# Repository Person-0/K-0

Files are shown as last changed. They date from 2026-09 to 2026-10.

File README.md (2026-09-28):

# **K-0**

75% Keyboard with thocky switches. USB-C / BLE connectivity, fully custom 3d printed case + PCB.

## The Idea

Always wanted to design a keyboard for myself. Decided to finally go for it.

After searching online about various keyboards and switches, I realized I love deep thocky-sounding keyboards, so I selected the `Akko Bittersweet` switches. They are tactile switches with an operating force of 48 ± 5gf and tactile force of 60 ± 5gf. ([more switch specs](https://en.akkogear.com/product/bittersweet-switch-lubed/), [sound test](https://www.youtube.com/watch?v=nj9W8xXELII)).

The layout of the keyboard will be 60%, with no separate arrow keys or navigation cluster BUT with an added function keys row.

The microcontroller I have selected for this project is the `MDBT50Q-P1M nRF52840 Based BLE Module` for it's built-in bluetooth capabilities and good support ecosystem for similar projects. This will be paired up with a 1s (3.7V) LiPo battery with a suitable capacity + custom charging circuit which will be good enough for our usecase.

### Keyboard layout (from [keyboard-layout-editor.com](https://keyboard-layout-editor.com)):
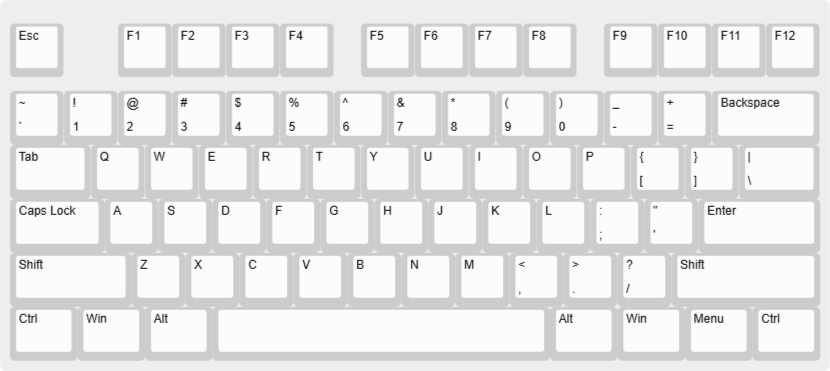
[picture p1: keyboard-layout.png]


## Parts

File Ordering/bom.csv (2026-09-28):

Reference | Qty | Value | Footprint | Datasheet | Manufacturer_Part_Number
C1,C2 | 2 | 1uF | Capacitor_SMD:C_0402_1005Metric | https://prod-parts-data.s3.amazonaws.com/CC0402KRX5R6BB105/datasheet/1_CC0402KRX5R6BB105-Yageo-datasheet-8324442.pdf | CC0402KRX5R6BB105
C3,C4 | 2 | 10uF | Capacitor_SMD:C_0402_1005Metric | https://prod-parts-data.s3.amazonaws.com/CC0402MRX5R5BB106/datasheet/1_CC0402MRX5R5BB106-Yageo-datasheet-140260304.pdf | CC0402MRX5R5BB106
C5 | 1 | 0.1uF | Capacitor_SMD:C_0402_1005Metric | https://prod-parts-data.s3.amazonaws.com/MC0402B104K160CT/datasheet/1_MC0402B104K160CT-Multicomp-datasheet-38887781.pdf | MC0402B104K160CT
D2,D3,D4,D5,D6,D7,D8,D9,D10,D11,D12,D13,D14,D15,D16,D17,D18,D19,D20,D21,D22,D23,D24,D25,D26,D27,D28,D29,D30,D31,D32,D33,D34,D35,D36,D37,D38,D39,D40,D41,D42,D43,D44,D45,D46,D47,D48,D49,D50,D51,D52,D53,D54,D55,D56,D57,D58,D59,D60,D61,D62,D63,D64,D65,D66,D67,D68,D69,D70,D73,D74,D75,D77,D81 | 74 | 1N4148WS | Diode_SMD:D_SOD-323F | https://prod-parts-data.s3.amazonaws.com/1N4148WS/datasheet/1_1N4148WS-ON-Semiconductor-datasheet-154551630.pdf | 1N4148WS
IC1 | 1 | BQ24040DSQR | BQ24040DSQR-lion:SON40P200X200X80-11N | http://www.ti.com/lit/gpn/bq24040 | BQ24040DSQR
IC2 | 1 | TPS63031DSKR | TPS63031DSKR-lion:SON50P250X250X80-11N-D | http://www.ti.com/general/docs/suppproductinfo.tsp?distId=10 | TPS63031DSKR
J1 | 1 | Display | Connector_PinHeader_2.54mm:PinHeader_1x08_P2.54mm_Vertical | ~
J2 | 1 | USB4216-03-A | USB421603A |  | USB4216-03-A
J4 | 1 | PG_LED | Connector_PinHeader_2.54mm:PinHeader_1x02_P2.54mm_Vertical | ~
J5 | 1 | CHRG_LED | Connector_PinHeader_2.54mm:PinHeader_1x02_P2.54mm_Vertical | ~
J6 | 1 | POWER_LED | Connector_PinHeader_2.54mm:PinHeader_1x02_P2.54mm_Vertical | ~
J7 | 1 | Mode Selector | Connector_PinHeader_2.54mm:PinHeader_1x03_P2.54mm_Vertical | ~
J8 | 1 | Mode Selector | Connector_PinHeader_2.54mm:PinHeader_1x04_P2.54mm_Vertical | ~
L2 | 1 | LPS3015-222MRC | LPS3015-222MRC:IND_LPS3015-222MRC | https://prod-parts-data.s3.amazonaws.com/LPS3015-222MRC/datasheet/1_LPS3015-222MRC-Coilcraft-datasheet-10792063.pdf | LPS3015-222MRC
MDBT50Q_1 | 1 | MDBT50Q_1 | RF_Module:Raytac_MDBT50Q | https://www.mouser.in/datasheet/3/1361/1/nRF52840_MDBT50Q_1MV2_MDBT50Q_P1MV2_Ver.L_spec.pdf | 113990583
R1,R2 | 2 | 5.1k | Resistor_SMD:R_0402_1005Metric | https://prod-parts-data.s3.amazonaws.com/CR0402-JW-512GLF/datasheet/1_CR0402-JW-512GLF-Bourns-datasheet-8723995.pdf | CR0402-JW-512GLF
R3 | 1 | 1k | Connector_PinHeader_2.54mm:PinHeader_1x02_P2.54mm_Vertical
R4 | 1 | 2k | Connector_PinHeader_2.54mm:PinHeader_1x02_P2.54mm_Vertical
R5 | 1 | 10k | Connector_PinHeader_2.54mm:PinHeader_1x02_P2.54mm_Vertical
R6,R7,R8 | 3 | 330 | Connector_PinHeader_2.54mm:PinHeader_1x02_P2.54mm_Vertical
R9 | 1 | 300k | Connector_PinHeader_2.54mm:PinHeader_1x02_P2.54mm_Vertical
R10 | 1 | 400k | Connector_PinHeader_2.54mm:PinHeader_1x02_P2.54mm_Vertical
SW1 | 1 | RotaryEncoder_Switch | Rotary_Encoder:RotaryEncoder_Alps_EC11E-Switch_Vertical_H20mm | ~
SW2 | 1 | ESC | Button_Switch_Keyboard:SW_Cherry_MX_1.00u_PCB | ~
SW3 | 1 | TILDE | Button_Switch_Keyboard:SW_Cherry_MX_1.00u_PCB | ~
SW4 | 1 | TAB | Button_Switch_Keyboard:SW_Cherry_MX_1.50u_PCB | ~
SW5 | 1 | CAPS | Button_Switch_Keyboard:SW_Cherry_MX_1.75u_PCB | ~
SW6 | 1 | LSHIFT | Button_Switch_Keyboard:SW_Cherry_MX_2.25u_PCB | ~
SW7 | 1 | LCTRL | Button_Switch_Keyboard:SW_Cherry_MX_1.25u_PCB | ~
SW8 | 1 | 1 | Button_Switch_Keyboard:SW_Cherry_MX_1.00u_PCB | ~
SW9 | 1 | Q | Button_Switch_Keyboard:SW_Cherry_MX_1.00u_PCB | ~
SW10 | 1 | A | Button_Switch_Keyboard:SW_Cherry_MX_1.00u_PCB | ~
SW11 | 1 | Z | Button_Switch_Keyboard:SW_Cherry_MX_1.00u_PCB | ~
SW12 | 1 | WIN | Button_Switch_Keyboard:SW_Cherry_MX_1.25u_PCB | ~
SW13 | 1 | F1 | Button_Switch_Keyboard:SW_Cherry_MX_1.00u_PCB | ~
SW14 | 1 | 2 | Button_Switch_Keyboard:SW_Cherry_MX_1.00u_PCB | ~
SW15 | 1 | W | Button_Switch_Keyboard:SW_Cherry_MX_1.00u_PCB | ~
SW16 | 1 | S | Button_Switch_Keyboard:SW_Cherry_MX_1.00u_PCB | ~
SW17 | 1 | X | Button_Switch_Keyboard:SW_Cherry_MX_1.00u_PCB | ~
SW18 | 1 | LALT | Button_Switch_Keyboard:SW_Cherry_MX_1.25u_PCB | ~
SW19 | 1 | F2 | Button_Switch_Keyboard:SW_Cherry_MX_1.00u_PCB | ~
SW20 | 1 | 3 | Button_Switch_Keyboard:SW_Cherry_MX_1.00u_PCB | ~
SW21 | 1 | E | Button_Switch_Keyboard:SW_Cherry_MX_1.00u_PCB | ~
SW22 | 1 | D | Button_Switch_Keyboard:SW_Cherry_MX_1.00u_PCB | ~
SW23 | 1 | C | Button_Switch_Keyboard:SW_Cherry_MX_1.00u_PCB | ~
SW24 | 1 | SPACE | Button_Switch_Keyboard:SW_Cherry_MX_6.25u_PCB | ~
SW25 | 1 | F3 | Button_Switch_Keyboard:SW_Cherry_MX_1.00u_PCB | ~
SW26 | 1 | 4 | Button_Switch_Keyboard:SW_Cherry_MX_1.00u_PCB | ~
SW27 | 1 | R | Button_Switch_Keyboard:SW_Cherry_MX_1.00u_PCB | ~
SW28 | 1 | F | Button_Switch_Keyboard:SW_Cherry_MX_1.00u_PCB | ~
SW29 | 1 | V | Button_Switch_Keyboard:SW_Cherry_MX_1.00u_PCB | ~
SW30 | 1 | F4 | Button_Switch_Keyboard:SW_Cherry_MX_1.00u_PCB | ~
SW31 | 1 | 5 | Button_Switch_Keyboard:SW_Cherry_MX_1.00u_PCB | ~
SW32 | 1 | T | Button_Switch_Keyboard:SW_Cherry_MX_1.00u_PCB | ~
SW33 | 1 | G | Button_Switch_Keyboard:SW_Cherry_MX_1.00u_PCB | ~
SW34 | 1 | B | Button_Switch_Keyboard:SW_Cherry_MX_1.00u_PCB | ~
SW35 | 1 | 6 | Button_Switch_Keyboard:SW_Cherry_MX_1.00u_PCB | ~
SW36 | 1 | Y | Button_Switch_Keyboard:SW_Cherry_MX_1.00u_PCB | ~
SW37 | 1 | H | Button_Switch_Keyboard:SW_Cherry_MX_1.00u_PCB | ~
SW38 | 1 | N | Button_Switch_Keyboard:SW_Cherry_MX_1.00u_PCB | ~
SW39 | 1 | F5 | Button_Switch_Keyboard:SW_Cherry_MX_1.00u_PCB | ~
SW40 | 1 | 7 | Button_Switch_Keyboard:SW_Cherry_MX_1.00u_PCB | ~
SW41 | 1 | U | Button_Switch_Keyboard:SW_Cherry_MX_1.00u_PCB | ~
SW42 | 1 | J | Button_Switch_Keyboard:SW_Cherry_MX_1.00u_PCB | ~
SW43 | 1 | M | Button_Switch_Keyboard:SW_Cherry_MX_1.00u_PCB | ~
SW44 | 1 | F6 | Button_Switch_Keyboard:SW_Cherry_MX_1.00u_PCB | ~
SW45 | 1 | 8 | Button_Switch_Keyboard:SW_Cherry_MX_1.00u_PCB | ~
SW46 | 1 | I | Button_Switch_Keyboard:SW_Cherry_MX_1.00u_PCB | ~
SW47 | 1 | K | Button_Switch_Keyboard:SW_Cherry_MX_1.00u_PCB | ~
SW48 | 1 | COMMA | Button_Switch_Keyboard:SW_Cherry_MX_1.00u_PCB | ~
SW49 | 1 | RALT | Button_Switch_Keyboard:SW_Cherry_MX_1.25u_PCB | ~
SW50 | 1 | F7 | Button_Switch_Keyboard:SW_Cherry_MX_1.00u_PCB | ~
SW51 | 1 | 9 | Button_Switch_Keyboard:SW_Cherry_MX_1.00u_PCB | ~
SW52 | 1 | O | Button_Switch_Keyboard:SW_Cherry_MX_1.00u_PCB | ~
SW53 | 1 | L | Button_Switch_Keyboard:SW_Cherry_MX_1.00u_PCB | ~
SW54 | 1 | DOT | Button_Switch_Keyboard:SW_Cherry_MX_1.00u_PCB | ~
SW55 | 1 | FN | Button_Switch_Keyboard:SW_Cherry_MX_1.25u_PCB | ~
SW56 | 1 | F8 | Button_Switch_Keyboard:SW_Cherry_MX_1.00u_PCB | ~
SW57 | 1 | 0 | Button_Switch_Keyboard:SW_Cherry_MX_1.00u_PCB | ~
SW58 | 1 | P | Button_Switch_Keyboard:SW_Cherry_MX_1.00u_PCB | ~
SW59 | 1 | SEMICOLON | Button_Switch_Keyboard:SW_Cherry_MX_1.00u_PCB | ~
SW60 | 1 | SLASH | Button_Switch_Keyboard:SW_Cherry_MX_1.00u_PCB | ~
SW61 | 1 | MENU | Button_Switch_Keyboard:SW_Cherry_MX_1.25u_PCB | ~
SW62 | 1 | MINUS | Button_Switch_Keyboard:SW_Cherry_MX_1.00u_PCB | ~
SW63 | 1 | SQBOPEN | Button_Switch_Keyboard:SW_Cherry_MX_1.00u_PCB | ~
SW64 | 1 | QUOTE | Button_Switch_Keyboard:SW_Cherry_MX_1.00u_PCB | ~
SW65 | 1 | RSHIFT | Button_Switch_Keyboard:SW_Cherry_MX_2.75u_PCB | ~
SW66 | 1 | RCTRL | Button_Switch_Keyboard:SW_Cherry_MX_1.25u_PCB | ~
SW67 | 1 | F9 | Button_Switch_Keyboard:SW_Cherry_MX_1.00u_PCB | ~
SW68 | 1 | EQUAL | Button_Switch_Keyboard:SW_Cherry_MX_1.00u_PCB | ~
SW69 | 1 | SQBCLOSE | Button_Switch_Keyboard:SW_Cherry_MX_1.00u_PCB | ~
SW70 | 1 | ENTER | Button_Switch_Keyboard:SW_Cherry_MX_2.25u_PCB | ~
SW73 | 1 | F10 | Button_Switch_Keyboard:SW_Cherry_MX_1.00u_PCB | ~
SW74 | 1 | BACKSPACE | Button_Switch_Keyboard:SW_Cherry_MX_2.00u_PCB | ~
SW75 | 1 | FWDSLASH | Button_Switch_Keyboard:SW_Cherry_MX_1.50u_PCB | ~
SW77 | 1 | F11 | Button_Switch_Keyboard:SW_Cherry_MX_1.00u_PCB | ~
SW81 | 1 | F12 | Button_Switch_Keyboard:SW_Cherry_MX_1.00u_PCB | ~

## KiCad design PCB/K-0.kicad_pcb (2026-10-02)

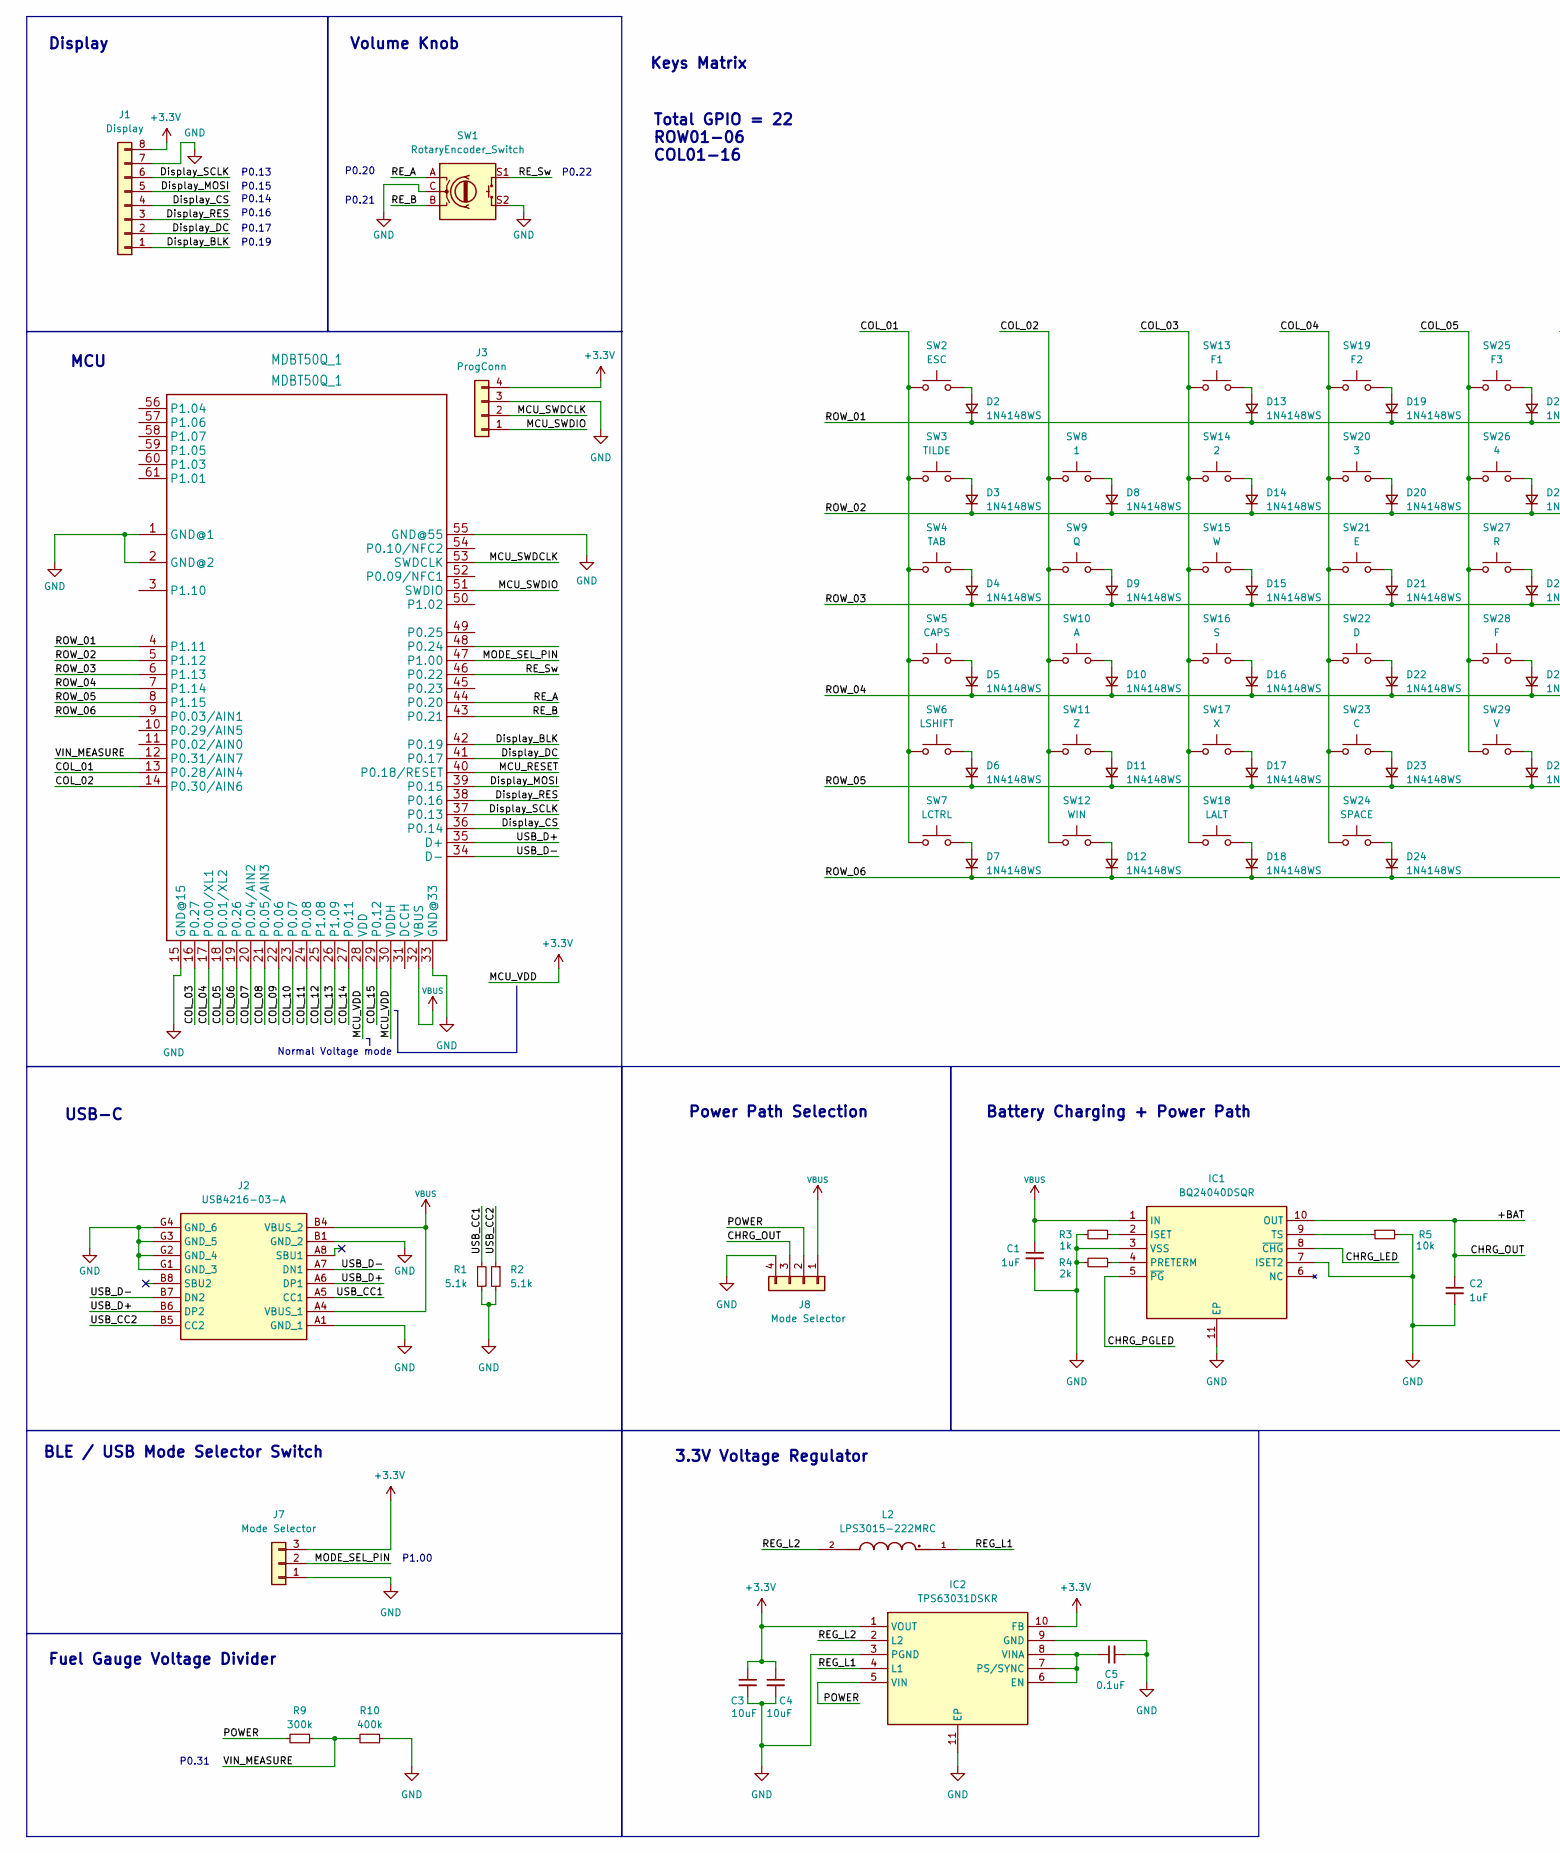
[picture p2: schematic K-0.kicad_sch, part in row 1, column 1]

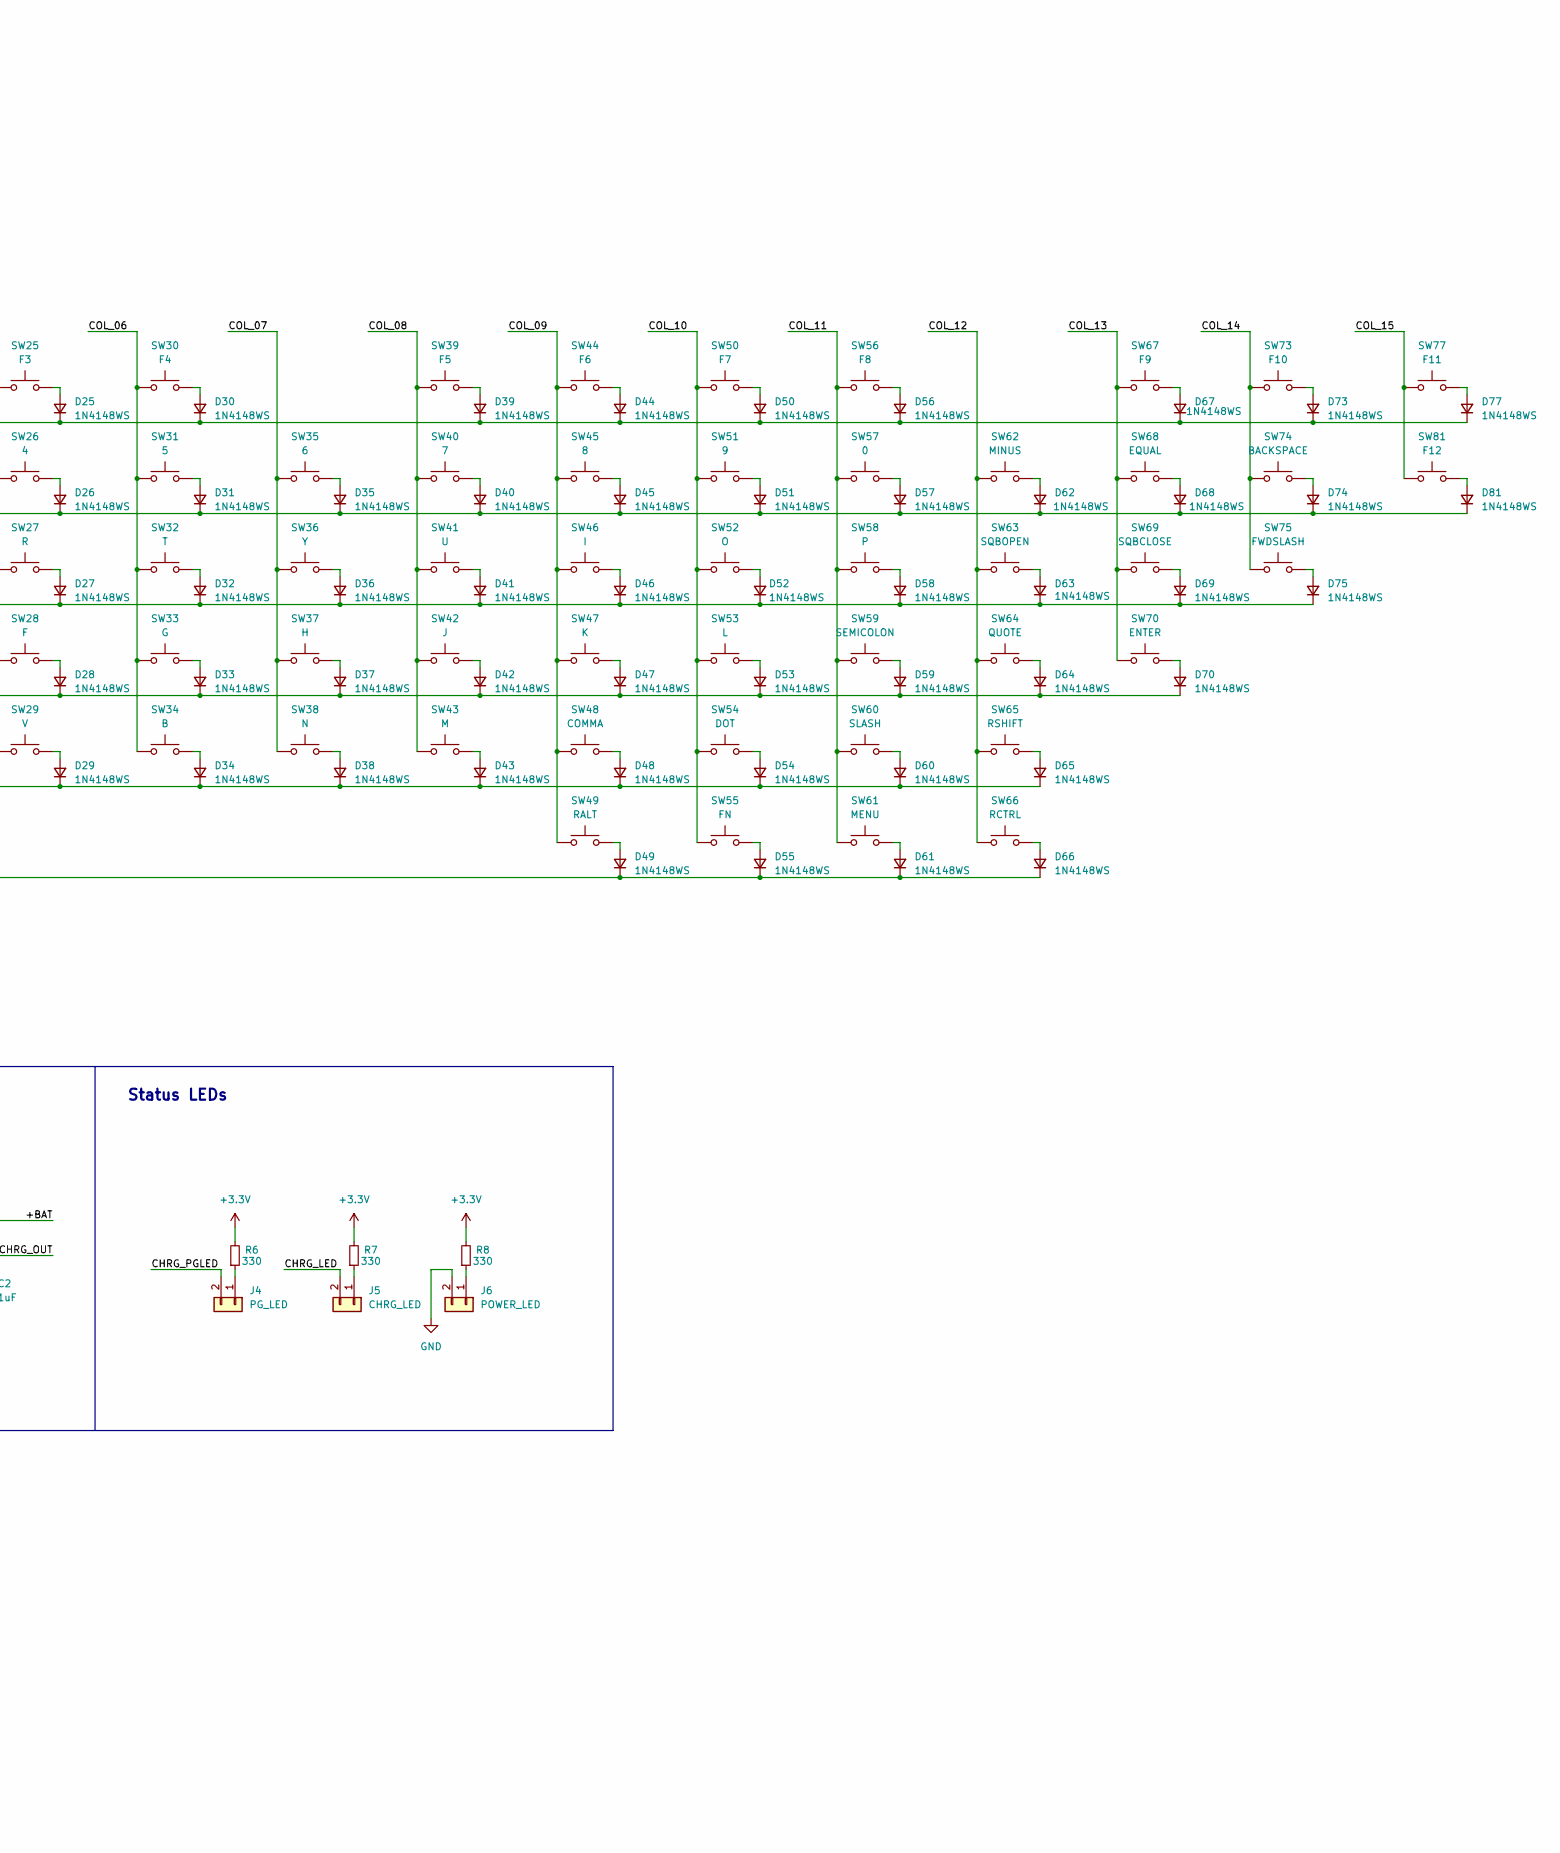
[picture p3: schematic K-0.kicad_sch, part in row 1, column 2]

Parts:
C1, C2: 1uF; C_0402_1005Metric; Manufacturer_Part_Number CC0402KRX5R6BB105
C3, C4: 10uF; C_0402_1005Metric; Manufacturer_Part_Number CC0402MRX5R5BB106
C5: 0.1uF; C_0402_1005Metric; Manufacturer_Part_Number MC0402B104K160CT
D2, D3, D4, D5, D6, D7, D8, D9, D10, D11, D12, D13, D14, D15, D16, D17, D18, D19, D20, D21, D22, D23, D24, D25, D26, D27, D28, D29, D30, D31, D32, D33, D34, D35, D36, D37, D38, D39, D40, D41, D42, D43, D44, D45, D46, D47, D48, D49, D50, D51, D52, D53, D54, D55, D56, D57, D58, D59, D60, D61, D62, D63, D64, D65, D66, D67, D68, D69, D70, D73, D74, D75, D77, D81: 1N4148WS; D_SOD-323F; Manufacturer_Part_Number 1N4148WS
IC1: BQ24040DSQR; SON40P200X200X80-11N; Mouser Part Number 595-BQ24040DSQR
IC2: TPS63031DSKR; SON50P250X250X80-11N-D; Mouser Part Number 595-TPS63031DSKR
J1: Display; PinHeader_1x08_P2.54mm_Vertical
J2: USB4216-03-A; USB421603A; Mouser Part Number 640-USB4216-03-A
J3: ProgConn; PinHeader_1x04_P2.54mm_Vertical
J4: PG_LED; PinHeader_1x02_P2.54mm_Vertical
J5: CHRG_LED; PinHeader_1x02_P2.54mm_Vertical
J6: POWER_LED; PinHeader_1x02_P2.54mm_Vertical
J7: Mode Selector; PinHeader_1x03_P2.54mm_Vertical
J8: Mode Selector; PinHeader_1x04_P2.54mm_Vertical
L2: LPS3015-222MRC; IND_LPS3015-222MRC; PARTREV 12/13/21
MDBT50Q_1: MDBT50Q_1; Raytac_MDBT50Q; Manufacturer_Part_Number 113990583
R1, R2: 5.1k; R_0402_1005Metric; Manufacturer_Part_Number CR0402-JW-512GLF
R3: 1k; PinHeader_1x02_P2.54mm_Vertical
R4: 2k; PinHeader_1x02_P2.54mm_Vertical
R5: 10k; PinHeader_1x02_P2.54mm_Vertical
R6, R7, R8: 330; PinHeader_1x02_P2.54mm_Vertical
R9: 300k; PinHeader_1x02_P2.54mm_Vertical
R10: 400k; PinHeader_1x02_P2.54mm_Vertical
SW1: RotaryEncoder_Switch; RotaryEncoder_Alps_EC11E-Switch_Vertical_H20mm
SW2: ESC; SW_Cherry_MX_1.00u_PCB
SW3: TILDE; SW_Cherry_MX_1.00u_PCB
SW4: TAB; SW_Cherry_MX_1.50u_PCB
SW5: CAPS; SW_Cherry_MX_1.75u_PCB
SW6: LSHIFT; SW_Cherry_MX_2.25u_PCB
SW7: LCTRL; SW_Cherry_MX_1.25u_PCB
SW8: 1; SW_Cherry_MX_1.00u_PCB
SW9: Q; SW_Cherry_MX_1.00u_PCB
SW10: A; SW_Cherry_MX_1.00u_PCB
SW11: Z; SW_Cherry_MX_1.00u_PCB
SW12: WIN; SW_Cherry_MX_1.25u_PCB
SW13: F1; SW_Cherry_MX_1.00u_PCB
SW14: 2; SW_Cherry_MX_1.00u_PCB
SW15: W; SW_Cherry_MX_1.00u_PCB
SW16: S; SW_Cherry_MX_1.00u_PCB
SW17: X; SW_Cherry_MX_1.00u_PCB
SW18: LALT; SW_Cherry_MX_1.25u_PCB
SW19: F2; SW_Cherry_MX_1.00u_PCB
SW20: 3; SW_Cherry_MX_1.00u_PCB
SW21: E; SW_Cherry_MX_1.00u_PCB
SW22: D; SW_Cherry_MX_1.00u_PCB
SW23: C; SW_Cherry_MX_1.00u_PCB
SW24: SPACE; SW_Cherry_MX_6.25u_PCB
SW25: F3; SW_Cherry_MX_1.00u_PCB
SW26: 4; SW_Cherry_MX_1.00u_PCB
SW27: R; SW_Cherry_MX_1.00u_PCB
SW28: F; SW_Cherry_MX_1.00u_PCB
SW29: V; SW_Cherry_MX_1.00u_PCB
SW30: F4; SW_Cherry_MX_1.00u_PCB
SW31: 5; SW_Cherry_MX_1.00u_PCB
SW32: T; SW_Cherry_MX_1.00u_PCB
SW33: G; SW_Cherry_MX_1.00u_PCB
SW34: B; SW_Cherry_MX_1.00u_PCB
SW35: 6; SW_Cherry_MX_1.00u_PCB
SW36: Y; SW_Cherry_MX_1.00u_PCB
SW37: H; SW_Cherry_MX_1.00u_PCB
SW38: N; SW_Cherry_MX_1.00u_PCB
SW39: F5; SW_Cherry_MX_1.00u_PCB
SW40: 7; SW_Cherry_MX_1.00u_PCB
SW41: U; SW_Cherry_MX_1.00u_PCB
SW42: J; SW_Cherry_MX_1.00u_PCB
SW43: M; SW_Cherry_MX_1.00u_PCB
SW44: F6; SW_Cherry_MX_1.00u_PCB
SW45: 8; SW_Cherry_MX_1.00u_PCB
SW46: I; SW_Cherry_MX_1.00u_PCB
SW47: K; SW_Cherry_MX_1.00u_PCB
SW48: COMMA; SW_Cherry_MX_1.00u_PCB
SW49: RALT; SW_Cherry_MX_1.25u_PCB
SW50: F7; SW_Cherry_MX_1.00u_PCB
SW51: 9; SW_Cherry_MX_1.00u_PCB
SW52: O; SW_Cherry_MX_1.00u_PCB
SW53: L; SW_Cherry_MX_1.00u_PCB
SW54: DOT; SW_Cherry_MX_1.00u_PCB
SW55: FN; SW_Cherry_MX_1.25u_PCB
SW56: F8; SW_Cherry_MX_1.00u_PCB
SW57: 0; SW_Cherry_MX_1.00u_PCB
SW58: P; SW_Cherry_MX_1.00u_PCB
SW59: SEMICOLON; SW_Cherry_MX_1.00u_PCB
SW60: SLASH; SW_Cherry_MX_1.00u_PCB
SW61: MENU; SW_Cherry_MX_1.25u_PCB
SW62: MINUS; SW_Cherry_MX_1.00u_PCB
SW63: SQBOPEN; SW_Cherry_MX_1.00u_PCB
SW64: QUOTE; SW_Cherry_MX_1.00u_PCB
SW65: RSHIFT; SW_Cherry_MX_2.75u_PCB
SW66: RCTRL; SW_Cherry_MX_1.25u_PCB
SW67: F9; SW_Cherry_MX_1.00u_PCB
SW68: EQUAL; SW_Cherry_MX_1.00u_PCB
SW69: SQBCLOSE; SW_Cherry_MX_1.00u_PCB
SW70: ENTER; SW_Cherry_MX_2.25u_PCB
SW73: F10; SW_Cherry_MX_1.00u_PCB
SW74: BACKSPACE; SW_Cherry_MX_2.00u_PCB
SW75: FWDSLASH; SW_Cherry_MX_1.50u_PCB
SW77: F11; SW_Cherry_MX_1.00u_PCB
SW81: F12; SW_Cherry_MX_1.00u_PCB

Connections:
+3.3V: C3.1, C4.1, IC2.1 (VOUT), IC2.10 (FB), J1.8, J3.4, J7.3, MDBT50Q_1.28 (VDD), MDBT50Q_1.30 (VDDH), R6.2, R7.2, R8.2
/+BAT: C2.1, IC1.10 (OUT), J8.3
/CHRG_LED: IC1.8 (~CHG), J5.2
/CHRG_PGLED: IC1.5 (~PG), J4.2
/COL_01: MDBT50Q_1.13 (P0.28/AIN4), SW2.1, SW3.1, SW4.1, SW5.1, SW6.1, SW7.1
/COL_02: MDBT50Q_1.14 (P0.30/AIN6), SW8.1, SW9.1, SW10.1, SW11.1, SW12.1
/COL_03: MDBT50Q_1.16 (P0.27), SW13.1, SW14.1, SW15.1, SW16.1, SW17.1, SW18.1
/COL_04: MDBT50Q_1.17 (P0.00/XL1), SW19.1, SW20.1, SW21.1, SW22.1, SW23.1, SW24.1
/COL_05: MDBT50Q_1.18 (P0.01/XL2), SW25.1, SW26.1, SW27.1, SW28.1, SW29.1
/COL_06: MDBT50Q_1.19 (P0.26), SW30.1, SW31.1, SW32.1, SW33.1, SW34.1
/COL_07: MDBT50Q_1.20 (P0.04/AIN2), SW35.1, SW36.1, SW37.1, SW38.1
/COL_08: MDBT50Q_1.21 (P0.05/AIN3), SW39.1, SW40.1, SW41.1, SW42.1, SW43.1
/COL_09: MDBT50Q_1.22 (P0.06), SW44.1, SW45.1, SW46.1, SW47.1, SW48.1, SW49.1
/COL_10: MDBT50Q_1.23 (P0.07), SW50.1, SW51.1, SW52.1, SW53.1, SW54.1, SW55.1
/COL_11: MDBT50Q_1.24 (P0.08), SW56.1, SW57.1, SW58.1, SW59.1, SW60.1, SW61.1
/COL_12: MDBT50Q_1.25 (P1.08), SW62.1, SW63.1, SW64.1, SW65.1, SW66.1
/COL_13: MDBT50Q_1.26 (P1.09), SW67.1, SW68.1, SW69.1, SW70.1
/COL_14: MDBT50Q_1.27 (P0.11), SW73.1, SW74.1, SW75.1
/COL_15: MDBT50Q_1.29 (P0.12), SW77.1, SW81.1
/Display_BLK: J1.1, MDBT50Q_1.42 (P0.19)
/Display_CS: J1.4, MDBT50Q_1.36 (P0.14)
/Display_DC: J1.2, MDBT50Q_1.41 (P0.17)
/Display_MOSI: J1.5, MDBT50Q_1.39 (P0.15)
/Display_RES: J1.3, MDBT50Q_1.38 (P0.16)
/Display_SCLK: J1.6, MDBT50Q_1.37 (P0.13)
/MCU_RESET: MDBT50Q_1.40 (P0.18/RESET)
/MCU_SWDCLK: J3.2, MDBT50Q_1.53 (SWDCLK)
/MCU_SWDIO: J3.1, MDBT50Q_1.51 (SWDIO)
/MODE_SEL_PIN: J7.2, MDBT50Q_1.47 (P1.00)
/POWER: IC2.5 (VIN), J8.2, R9.2
/REG_L1: IC2.4 (L1), L2.1
/REG_L2: IC2.2 (L2), L2.2
/RE_A: MDBT50Q_1.44 (P0.20), SW1.A
/RE_B: MDBT50Q_1.43 (P0.21), SW1.B
/RE_Sw: MDBT50Q_1.46 (P0.22), SW1.S1
/ROW_01: D2.1 (K), D13.1 (K), D19.1 (K), D25.1 (K), D30.1 (K), D39.1 (K), D44.1 (K), D50.1 (K), D56.1 (K), D67.1 (K), D73.1 (K), D77.1 (K), MDBT50Q_1.4 (P1.11)
/ROW_02: D3.1 (K), D8.1 (K), D14.1 (K), D20.1 (K), D26.1 (K), D31.1 (K), D35.1 (K), D40.1 (K), D45.1 (K), D51.1 (K), D57.1 (K), D62.1 (K), D68.1 (K), D74.1 (K), D81.1 (K), MDBT50Q_1.5 (P1.12)
/ROW_03: D4.1 (K), D9.1 (K), D15.1 (K), D21.1 (K), D27.1 (K), D32.1 (K), D36.1 (K), D41.1 (K), D46.1 (K), D52.1 (K), D58.1 (K), D63.1 (K), D69.1 (K), D75.1 (K), MDBT50Q_1.6 (P1.13)
/ROW_04: D5.1 (K), D10.1 (K), D16.1 (K), D22.1 (K), D28.1 (K), D33.1 (K), D37.1 (K), D42.1 (K), D47.1 (K), D53.1 (K), D59.1 (K), D64.1 (K), D70.1 (K), MDBT50Q_1.7 (P1.14)
/ROW_05: D6.1 (K), D11.1 (K), D17.1 (K), D23.1 (K), D29.1 (K), D34.1 (K), D38.1 (K), D43.1 (K), D48.1 (K), D54.1 (K), D60.1 (K), D65.1 (K), MDBT50Q_1.8 (P1.15)
/ROW_06: D7.1 (K), D12.1 (K), D18.1 (K), D24.1 (K), D49.1 (K), D55.1 (K), D61.1 (K), D66.1 (K), MDBT50Q_1.9 (P0.03/AIN1)
/USB_CC1: J2.A5 (CC1), R1.1
/USB_CC2: J2.B5 (CC2), R2.1
/USB_D+: J2.A6 (DP1), J2.B6 (DP2), MDBT50Q_1.35 (D+)
/USB_D-: J2.A7 (DN1), J2.B7 (DN2), MDBT50Q_1.34 (D-)
/VIN_MEASURE: MDBT50Q_1.12 (P0.31/AIN7), R9.1, R10.2
GND: C1.2, C2.2, C3.2, C4.2, C5.2, IC1.3 (VSS), IC1.7 (ISET2), IC1.11 (EP), IC2.3 (PGND), IC2.9 (GND), IC2.11 (EP), J1.7, J2.A1 (GND_1), J2.B1 (GND_2), J2.G1 (GND_3), J2.G2 (GND_4), J2.G3 (GND_5), J2.G4 (GND_6), J3.3, J6.2, J7.1, J8.4, MDBT50Q_1.1 (GND@1), MDBT50Q_1.2 (GND@2), MDBT50Q_1.15 (GND@15), MDBT50Q_1.33 (GND@33), MDBT50Q_1.55 (GND@55), R1.2, R2.2, R3.2, R4.2, R5.2, R10.1, SW1.C, SW1.S2
unnamed: D2.2 (A), SW2.2
unnamed: D3.2 (A), SW3.2
unnamed: D4.2 (A), SW4.2
unnamed: D5.2 (A), SW5.2
unnamed: D6.2 (A), SW6.2
unnamed: D7.2 (A), SW7.2
unnamed: D8.2 (A), SW8.2
unnamed: D9.2 (A), SW9.2
unnamed: D10.2 (A), SW10.2
unnamed: D11.2 (A), SW11.2
unnamed: D12.2 (A), SW12.2
unnamed: D13.2 (A), SW13.2
unnamed: D14.2 (A), SW14.2
unnamed: D15.2 (A), SW15.2
unnamed: D16.2 (A), SW16.2
unnamed: D17.2 (A), SW17.2
unnamed: D18.2 (A), SW18.2
unnamed: D19.2 (A), SW19.2
unnamed: D20.2 (A), SW20.2
unnamed: D21.2 (A), SW21.2
unnamed: D22.2 (A), SW22.2
unnamed: D23.2 (A), SW23.2
unnamed: D24.2 (A), SW24.2
unnamed: D25.2 (A), SW25.2
unnamed: D26.2 (A), SW26.2
unnamed: D27.2 (A), SW27.2
unnamed: D28.2 (A), SW28.2
unnamed: D29.2 (A), SW29.2
unnamed: D30.2 (A), SW30.2
unnamed: D31.2 (A), SW31.2
unnamed: D32.2 (A), SW32.2
unnamed: D33.2 (A), SW33.2
unnamed: D34.2 (A), SW34.2
unnamed: D35.2 (A), SW35.2
unnamed: D36.2 (A), SW36.2
unnamed: D37.2 (A), SW37.2
unnamed: D38.2 (A), SW38.2
unnamed: D39.2 (A), SW39.2
unnamed: D40.2 (A), SW40.2
unnamed: D41.2 (A), SW41.2
unnamed: D42.2 (A), SW42.2
unnamed: D43.2 (A), SW43.2
unnamed: D44.2 (A), SW44.2
unnamed: D45.2 (A), SW45.2
unnamed: D46.2 (A), SW46.2
unnamed: D47.2 (A), SW47.2
unnamed: D48.2 (A), SW48.2
unnamed: D49.2 (A), SW49.2
unnamed: D50.2 (A), SW50.2
unnamed: D51.2 (A), SW51.2
unnamed: D52.2 (A), SW52.2
unnamed: D53.2 (A), SW53.2
unnamed: D54.2 (A), SW54.2
unnamed: D55.2 (A), SW55.2
unnamed: D56.2 (A), SW56.2
unnamed: D57.2 (A), SW57.2
unnamed: D58.2 (A), SW58.2
unnamed: D59.2 (A), SW59.2
unnamed: D60.2 (A), SW60.2
unnamed: D61.2 (A), SW61.2
unnamed: D62.2 (A), SW62.2
unnamed: D63.2 (A), SW63.2
unnamed: D64.2 (A), SW64.2
unnamed: D65.2 (A), SW65.2
unnamed: D66.2 (A), SW66.2
unnamed: D67.2 (A), SW67.2
unnamed: D68.2 (A), SW68.2
unnamed: D69.2 (A), SW69.2
unnamed: D70.2 (A), SW70.2
unnamed: D73.2 (A), SW73.2
unnamed: D74.2 (A), SW74.2
unnamed: D75.2 (A), SW75.2
unnamed: D77.2 (A), SW77.2
unnamed: D81.2 (A), SW81.2
unnamed: IC1.2 (ISET), R3.1
unnamed: IC1.4 (PRETERM), R4.1
unnamed: IC1.9 (TS), R5.1
unnamed: C5.1, IC2.6 (EN), IC2.7 (PS/SYNC), IC2.8 (VINA)
unnamed: J4.1, R6.1
unnamed: J5.1, R7.1
unnamed: J6.1, R8.1
VBUS: C1.1, IC1.1 (IN), J2.A4 (VBUS_1), J2.B4 (VBUS_2), J8.1, MDBT50Q_1.32 (VBUS)

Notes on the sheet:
P0.16
P0.20
USB-C
P0.14
BLE / USB Mode Selector Switch
Status LEDs
Normal Voltage mode
P0.22
P0.19
3.3V Voltage Regulator
P0.17
Battery Charging + Power Path
Display
P0.13
Volume Knob
P0.15
P0.31
MCU
P0.21
Keys Matrix
P1.00
Total GPIO = 22 ROW01-06 COL01-16
Power Path Selection
Fuel Gauge Voltage Divider

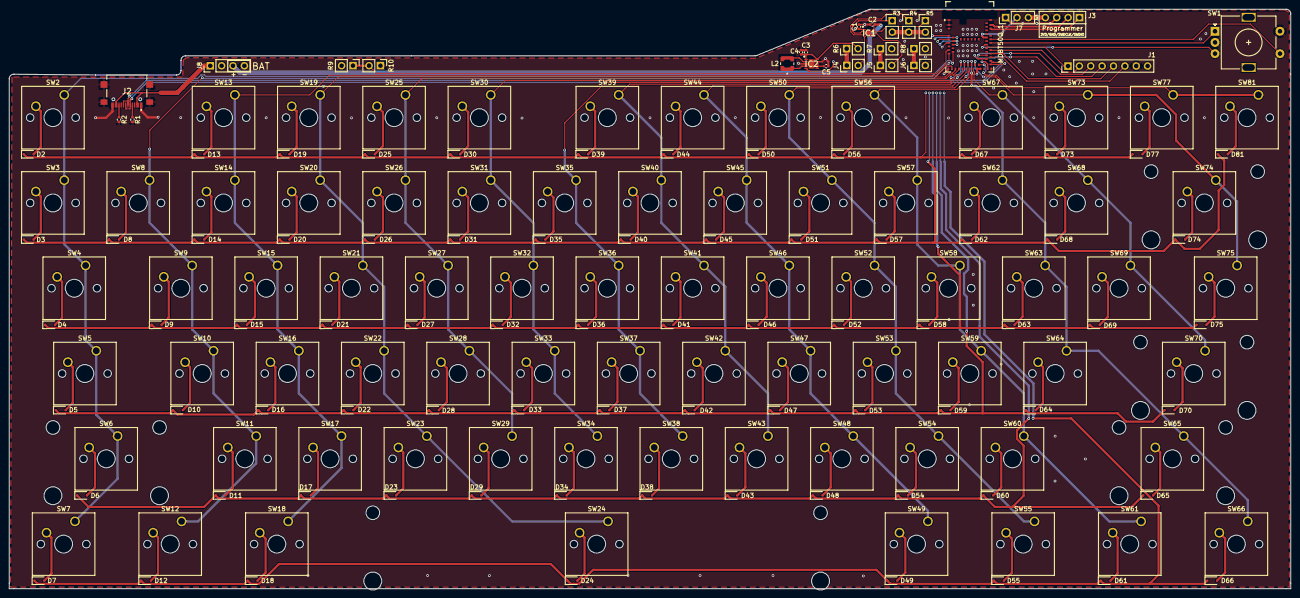
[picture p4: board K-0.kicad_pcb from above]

Board: 4 copper layers, 286.2 x 129.4 mm, 176 parts (0 on the bottom side), 128 nets.

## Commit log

2026-09-24 added dispaly, knob, keys schematics
    [K-0.kicad_pcb, K-0.kicad_sch]
2026-09-24 added footprints for display connector and know
    [K-0.kicad_sch]
2026-09-27 finished schematics
    [K-0.kicad_sch, bom.csv]
2026-09-28 initial keys layout
    [K-0.kicad_pcb, K-0.kicad_sch]
2026-09-28 layout rev1
    [K-0.kicad_pcb, K-0.kicad_sch]
2026-09-28 bom update acc to new layout
    [bom.csv]
2026-09-29 schematics update + routing progress
    [K-0.kicad_pcb, K-0.kicad_sch]
2026-10-02 routing almost finished
    [K-0.kicad_pcb, K-0.kicad_sch]
2026-10-09 pcb finished
2026-10-10 setup different boards for cost reduction trial
2026-10-10 added teardrops on daughter board
2026-10-11 updated daughter board
2026-10-11 main board rev1
2026-10-11 pcb finish rev2
2026-10-11 moved pcb step file to correct location
